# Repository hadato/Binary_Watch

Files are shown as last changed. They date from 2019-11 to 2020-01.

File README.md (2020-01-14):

# Binary Watch

This is a project of binary watch which is able to show time, date and its battery level. Three side LEDs show what is currently on display. The watch is based on an ATMega328p and a PCF8563 real-time clock. All control is done using one press bottom. Light-sensing is implemented for brightness adjustments. 

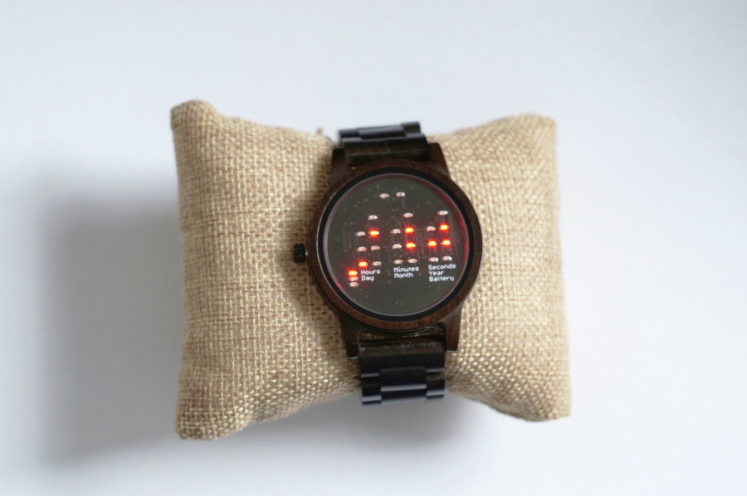
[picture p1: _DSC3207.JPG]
Final prototype


## Description

### Repository and Project Status

The repository contains a first prototype of the watch to be implemented in a wooden hand watch. Both source code, board design files are included. The first prototype has been implemented on a breadboard and is fully functional. The second prototype was build in a wooden wrist watch and is fully functional.

### Main Watch Components
- 25 LEDs
- ATMega328p microcontroller
- PCF8563 real-time clock
- Small tactile switch
- MCP73831T Li-Ion battery charger
- Rechargeable 2032 Li-Ion battery
- Phototransistor for LED intensity adjustment
- USB connector for charging

### Working Principle

The main part of the project is based on an 8-bit microcontroller (uC) ATMega328p connected to the PCF8563 real-time clock (RTC) using I2C. The RTC keeps the correct time, whereas the uC is responsible for all logical operations, inputs from the button and LED output. When the button is pressed, the uC wakes up and the current time is read from the RTC. The time (hours, minutes, seconds) is displayed in a binary-coded decimal (BCD) format on the LEDs using multiplexing. If the button is pressed shortly once more, date (day, month, year) is displayed. Third short press shows the battery voltage. Another short press puts the uC to the sleep mode again. If the button is not pressed for more than 8 s, the uC goes to the sleep mode and all LED are turned off. If a longer press is performed, the watch goes into the sleep mode from either of the previous states. 

To enter the time-setting mode, the button has to be pressed for more than 1 s in either of the previously mentioned modes. If the time-setting mode is entered, a variable to be set starts to blink (first, variable second starts to blink). A short press increments the corresponding variable, longer press (over 0.25s) moves to the next variable (seconds -> minutes -> hours -> day -> month -> year), extra long press confirms the changes and makes the watch to return to the time-display mode.

To save the energy during the run-time and minimize the parts-count, the uC runs on an internal 1 MHz oscillator.

### Code

Note: As included, the code is working though it is still under development and far from being optimal.

The watch is programmed in C++ and is split into three different parts. For the communication with the RTC, twi.h and twi.cpp files were created. For the basic watch operation (button press, LED multiplexing, time reading/setting) a watch.h and watch.cpp files were created. The main.cpp then binds everything together. 

### Board Design

The board is designe using EAGLE and its lates version (9.5.1). The file Top_final shows a look of the watch, the files Top_copper and Bot_copper show the board design. Files BinaryWatch_v0_4_OptR_fix are the EAGLE files.

## Future Goals

- Improve the coding and commenting
- Making a more versatile design which can be used in different watches ranging from tiny hand watches to table/wall watches.
- Implement USB communication with PC to be able to conveniently set up time on the watch (different uC needed).

## Other Pictures
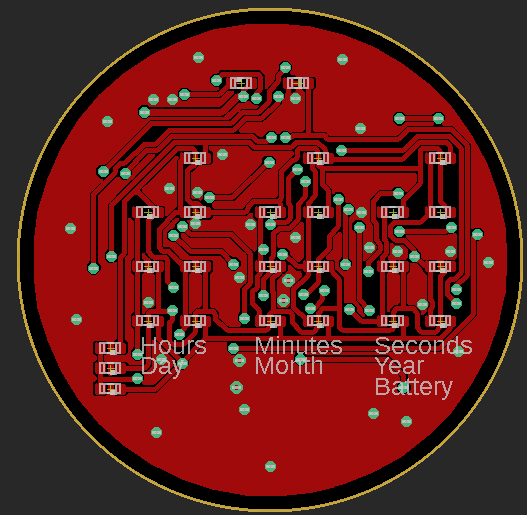
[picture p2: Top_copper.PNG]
TopCopper

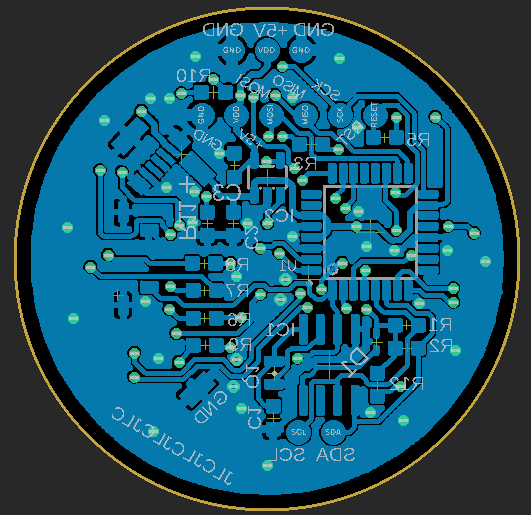
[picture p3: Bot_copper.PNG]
BotCopper

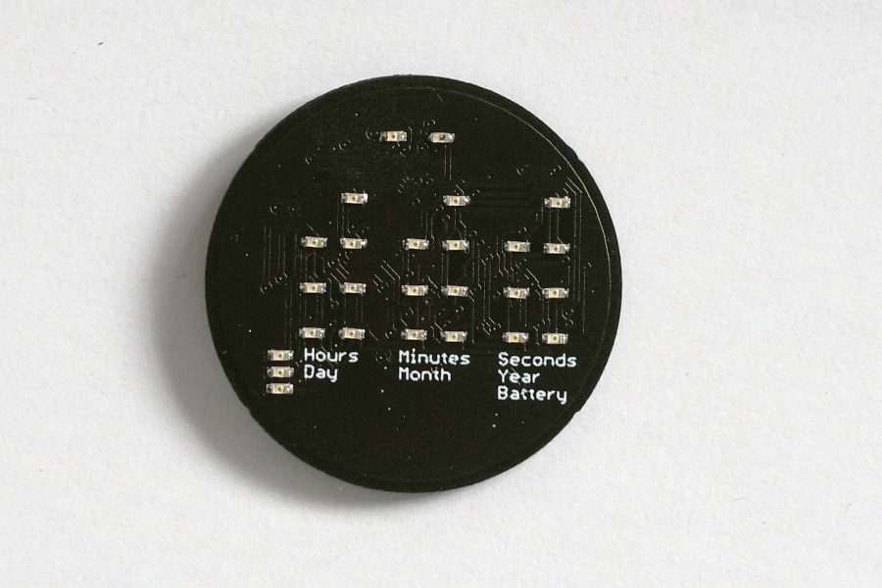
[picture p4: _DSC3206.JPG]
Top

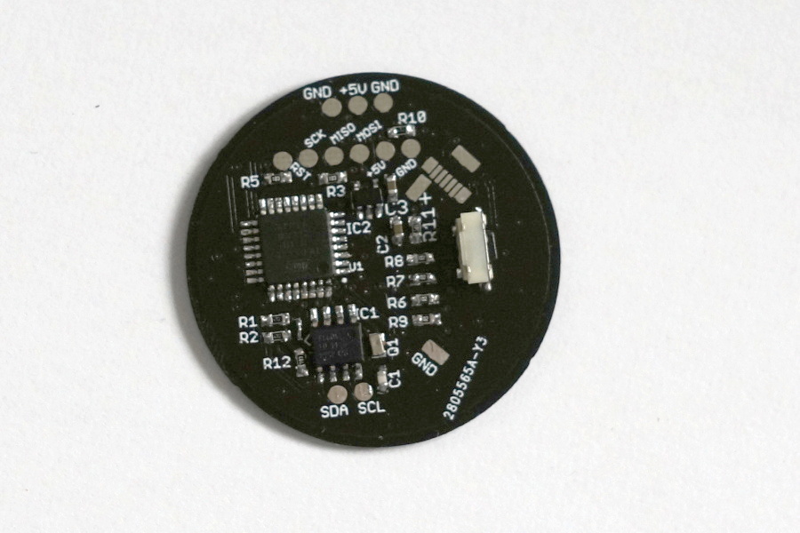
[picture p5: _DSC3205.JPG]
Bot


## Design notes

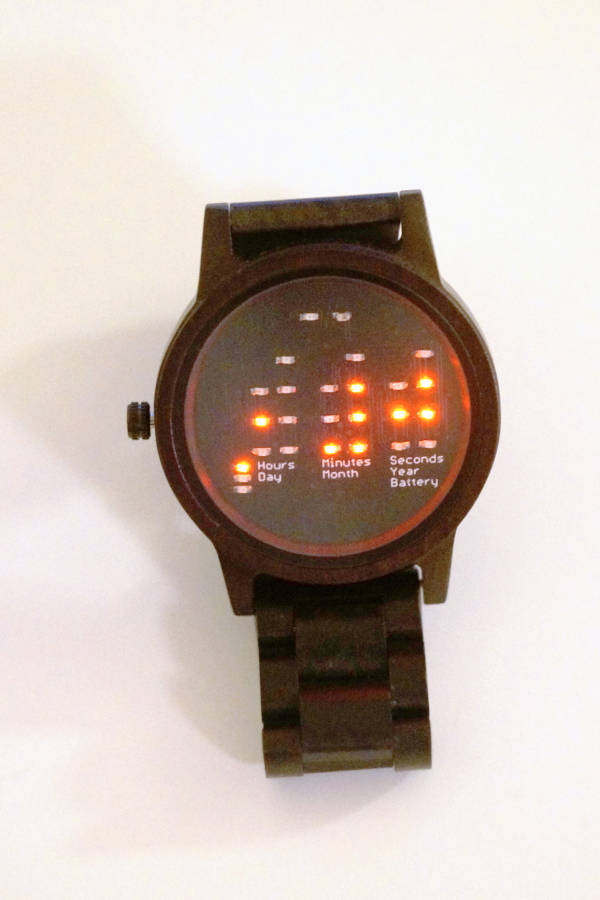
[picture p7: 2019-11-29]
FinalPototype.jpg

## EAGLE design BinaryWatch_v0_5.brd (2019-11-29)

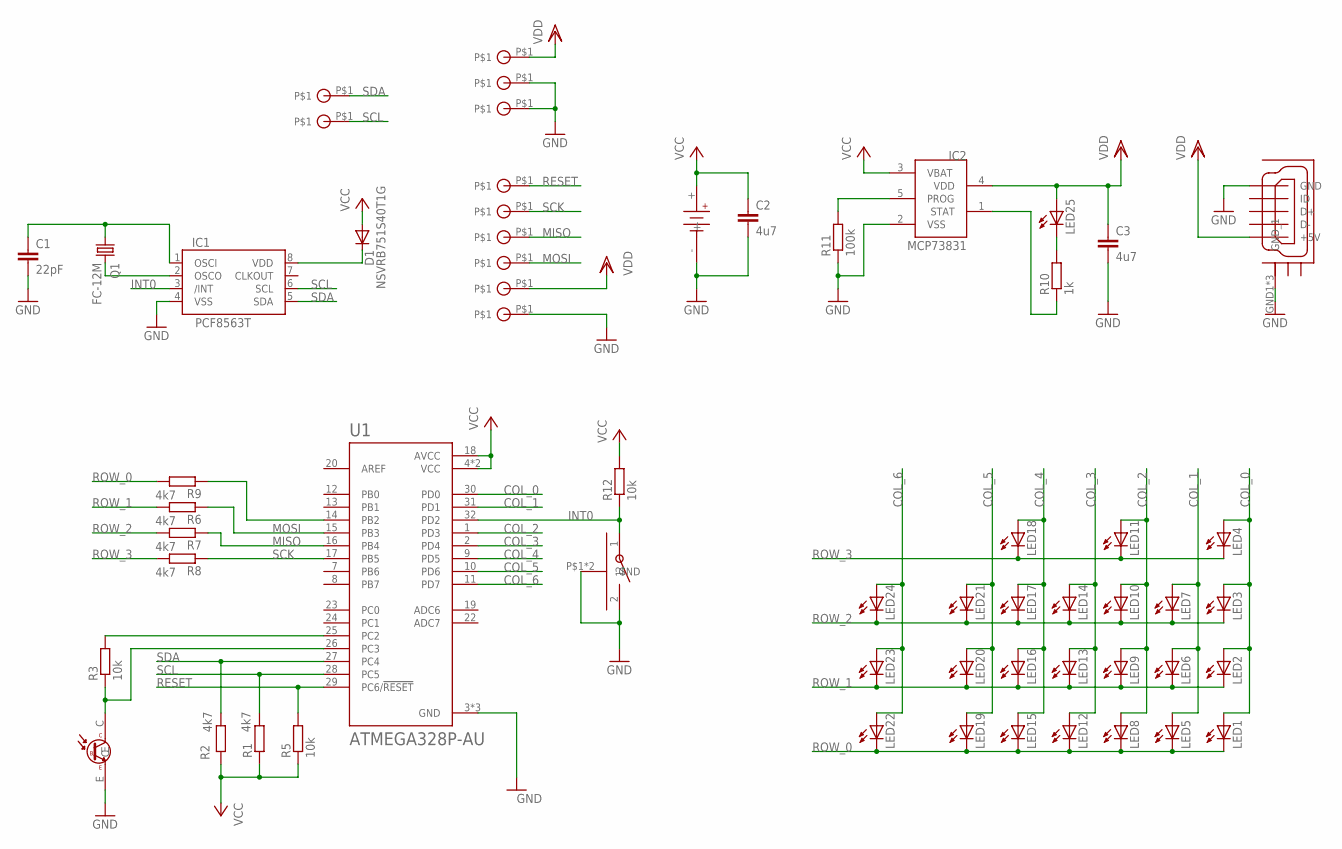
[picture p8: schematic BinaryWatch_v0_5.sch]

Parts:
C1: 22pF; C0603
C2, C3: 4u7; C0603
D1: NSVRB751S40T1G; SOD523
IC1: PCF8563T; SO8
IC2: MCP73831; SOT23-5L
LED1, LED2, LED3, LED4, LED5, LED6, LED7, LED8, LED9, LED10, LED11, LED12, LED13, LED14, LED15, LED16, LED17, LED18, LED19, LED20, LED21, LED22, LED23, LED24, LED25: LEDSML0603; SML0603
Q1: FC-12M
R1, R2, R6, R7, R8, R9: 4k7; R0603
R3, R5, R12: 10k; R0603
R10: 1k; R0603
R11: 100k; R0603
U1: ATMEGA328P-AU; QFP80P900X900X120-32N
U$1: 2032; 2032_45DEG
U$2, U$3, U$4, U$5, U$6, U$7, U$9, U$11, U$12, U$13, U$14: CONTACT_1_8MM
U$8: TACK_SWITCH; TL3330
U$10: MICRO_USB_VERTICAL
U$15: PHOTOTRANSISTOR_0603; PHOTO_TRANS_0603

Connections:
COL_0: LED1.A, LED2.A, LED3.A, LED4.A, U1.30 (PD0)
COL_1: LED5.A, LED6.A, LED7.A, U1.31 (PD1)
COL_2: LED8.A, LED9.A, LED10.A, LED11.A, U1.1 (PD3)
COL_3: LED12.A, LED13.A, LED14.A, U1.2 (PD4)
COL_4: LED15.A, LED16.A, LED17.A, LED18.A, U1.9 (PD5)
COL_5: LED19.A, LED20.A, LED21.A, U1.10 (PD6)
COL_6: LED22.A, LED23.A, LED24.A, U1.11 (PD7)
GND: C1.2, C2.2, C3.2, IC1.4 (VSS), IC2.2 (VSS), R11.1, U1.3 (GND), U1.5 (GND), U1.21 (GND), U$1.-, U$2.P$1, U$8.2, U$8.P$1 (GND), U$8.P$2 (GND), U$9.P$1, U$10.5 (GND), U$10.GND1 (GND_1), U$10.GND2 (GND_1), U$10.GND3 (GND_1), U$12.P$1, U$15.E
INT0: IC1.3 (/INT), R12.1, U1.32 (PD2), U$8.1
MISO: R7.1, U1.16 (PB4), U$5.P$1
MOSI: R6.1, U1.15 (PB3), U$4.P$1
unnamed: IC1.2 (OSCO), Q1.2
unnamed: C1.1, IC1.1 (OSCI), Q1.1
unnamed: R3.1, U1.26 (PC3), U$15.C
unnamed: R3.2, U1.25 (PC2)
unnamed: R9.1, U1.14 (PB2)
unnamed: D1.C, IC1.8 (VDD)
unnamed: IC2.1 (STAT), R10.1
unnamed: LED25.C, R10.2
unnamed: IC2.5 (PROG), R11.2
RESET: R5.2, U1.29 (PC6/!RESET), U$7.P$1
ROW_0: LED1.C, LED5.C, LED8.C, LED12.C, LED15.C, LED19.C, LED22.C, R9.2
ROW_1: LED2.C, LED6.C, LED9.C, LED13.C, LED16.C, LED20.C, LED23.C, R6.2
ROW_2: LED3.C, LED7.C, LED10.C, LED14.C, LED17.C, LED21.C, LED24.C, R7.2
ROW_3: LED4.C, LED11.C, LED18.C, R8.2
SCK: R8.1, U1.17 (PB5), U$6.P$1
SCL: IC1.6 (SCL), R1.2, U1.28 (PC5), U$14.P$1
SDA: IC1.5 (SDA), R2.2, U1.27 (PC4), U$13.P$1
VCC: C2.1, D1.A, IC2.3 (VBAT), R1.1, R2.1, R5.1, R12.2, U1.4 (VCC), U1.6 (VCC), U1.18 (AVCC), U$1.+
VDD: C3.1, IC2.4 (VDD), LED25.A, U$3.P$1, U$10.1 (+5V), U$11.P$1

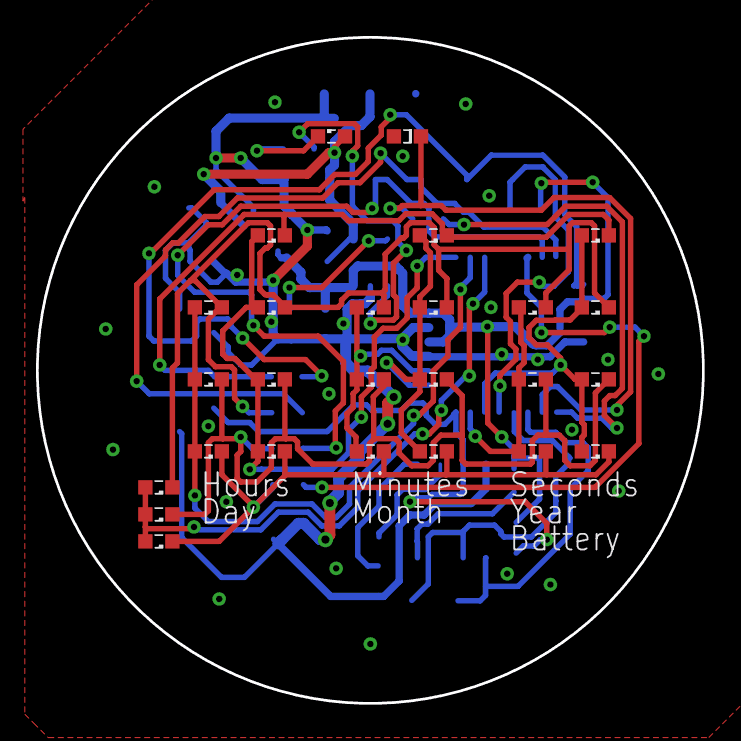
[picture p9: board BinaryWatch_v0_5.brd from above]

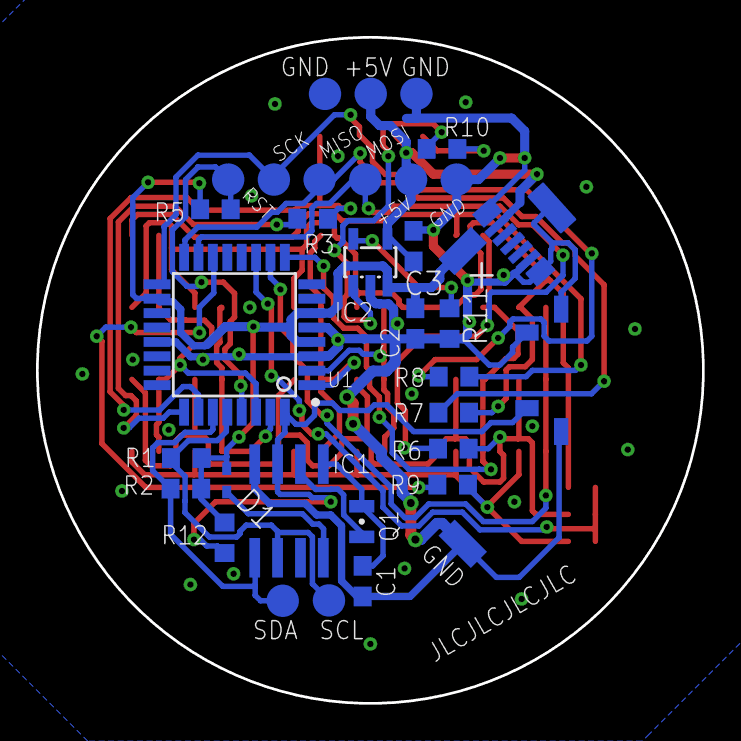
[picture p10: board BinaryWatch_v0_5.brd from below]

Board: 2 copper layers, 37.0 x 37.0 mm, 59 parts (33 on the bottom side), 30 nets.

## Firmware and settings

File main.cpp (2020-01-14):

/*
 * BinaryWatch_v0.1.cpp
 * Blink Test
 * Created: 7.10.2019 10:56:57
 * Author : Hadato
 */ 

#define F_CPU 1000000UL

#include <avr/io.h>
#include <util/delay.h>
#include <stdlib.h>
#include <avr/interrupt.h>
#include <avr/sleep.h>

#include "twi.h"
#include "watch.h"

int main(void){		
	//Wait for the power to get settled
	cli();
	_delay_ms(500);
	
	
	//Initialize the watch including all its functions	
	watch::init();		
		
	//Turn on all the LEDs for 1s to show that the chip has started working		
	WRITE_PORT(PORTB,0b00000000,0b00111100);
	WRITE_PORT(PORTD,0b11111111,0b11111011);
	
	_delay_ms(2000);
	sei();	
    
    while (1){
		
		
		_delay_ms(10);		
			
		//Update the time from the RT clock and save it to corresponding internal watch variables
		watch::update_TimeDate();
		
		//Measure the voltage and light intensity and set the LED brightness accordingly
 		watch::set_LED_intensity(watch::light);	//Set the intensity of LEDs accordingly
		watch::ADC_get_supply_light();			//Measure the supply voltage and the light intensity
		
		//Send the info to Arduino
		// watch::sentToArduino(watch::light);
		
		//Has to be called in the loop in order to get the state machine to work
		if(watch::pressed){			
			//Change the internal system state			
			watch::state = watch::state_machine(watch::state,watch::pressed);
			watch::pressed = NOT;			
		}
		
		//If the state is set to GO_SLEEP, turn-off all the LEDs and sleep the uC. Wake up and update after the sleep
		if (watch::state == GO_SLEEP){
			_delay_ms(20);
			//Disable all not needed modules and set all LED outputs low
			watch::set_all_pins_low_LED();				// Set all LED outputs low to save energy
			watch::ADC_disable();						// Disable ADC			
			//watch::PRR_disable_all();					// DIsable all modules in the sleep mode
			twi::disable_pull_ups();					// Disable pull-ups on TWI
			
			
			//Prepare for sleep and sleep
			sleep_enable();						//Enable sleep mode
			EIMSK  |= (1 << INT0);				//Turns on INT0 to enable wake up of the uC
			sleep_cpu();						//Go to sleep		
			
			//After sleep
			sleep_disable();
			watch::PRR_enable_ADC_Timer0();		//Turn on just the ADC and Timer0
				
			uint8_t voltage_low = 1;		
			while (voltage_low){
				watch::PRR_enable_ADC_Timer0();	//Turn on just the ADC and Timer0
				watch::ADC_get_supply_light();
				_delay_ms(15);					//Wait for the voltage measurement to complete
				if (watch::u_supply < 2.9){
					//watch::PRR_disable_all();		//Turn off all peripherals
					watch::set_all_pins_low_LED();	// Set all LED outputs low to save energy
					watch::ADC_disable();			// Disable ADC
					sleep_enable();
					sleep_cpu();
					sleep_disable();
				}else{
					voltage_low = 0;
				}
			}
			
			
			cli();						//Disable interrupts to safely change states and PRR register
			watch::PRR_enable_ADC_Timers_TWI();			//Turn on all peripherals except SPI and USART0
			
			
			// After sleep update of states and time from the watch. Disable the sleep, enable the 
			// pull-ups on Twi		
			twi::enable_pull_ups();		//Enable pull-ups on TWI
			
			//Reset internal states after sleep
			watch::pressed = NOT;
			watch::state   = AFTER_SLEEP;
				
			sei();						//Enable interrupts			
			
			//Update time and date and save it to the variables
			watch::set_LED_intensity(200);
			watch::update_TimeDate();					
		}			
    }
}

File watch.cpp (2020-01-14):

/*A source file for multiplexing
*	Timer0 is used for multiplexing
*	Timer1 is used for the button press and general timing needs
*
*
*/

#include "watch.h"
#include <avr/io.h>
#include <stdlib.h>
#include "twi.h"
#include <avr/interrupt.h>
#include <avr/sleep.h>

namespace watch{
	//Variables to store the current time from the RT clock
	Time time_DEC;			//Current time in DEC format
	Time time_BCD;			//Current time in BCD format
	Time time_DEC_new;		//New time to be set on the watch in DEC format
	Time time_BCD_new;		//New time to be set on the watch in BCD format
	uint8_t col;			//A variable to store current column to be displayed - used for multiplexing
	uint16_t press_how_long = 0;	//An internal variable to determine the length of the press
	uint8_t pressed = NOT;			//A variable for the length of the last press. Set to not-pressed
	float battery_level = 0;		//A variable to store the battery level (initialized to 0)
	State state = GO_SLEEP;			//A variable to indicate the current state of the watch. Set to enter the sleep mode
	float u_supply = 0;				//A variable to store the current voltage of the battery
	uint16_t u_supply_sum= 0;		//Raw sum of the battery voltage readouts
	float u_supply_show = 0;		//A variable to store the voltage of the battery to be displayed on the LEDs
	uint16_t blink_counter = 0;		//A counter for blinking function
	bool blink = true;				//Should the LEDs blink?
	uint8_t error = 0;				//An internal error variable
	uint8_t light = 255;			//A variable to store how much light it is outside (values from 0 (high light) - 255 (low light))
	uint8_t light_vect[] = {255,255,255,255};
	uint16_t light_sum = 0;
	adc_stat ADC_stat = MEASURE_LIGHT;		//A variable to store the ADC internal state
	uint8_t adc_counter = 0;				//Counter for the light average
	
	//Instance of the Twi class - communication with the RT clock
	twi Twi;	
}



ISR(BADISR_vect)
{
	// skip a random interrupt
}

////////////////////LED multiplexing and visualization //////////////////////////////// 
ISR(TIMER2_COMPA_vect){
	//dim the LEDs according to the light
	watch::clear_LED();
}

ISR(TIMER2_COMPB_vect){
	//set the LEDs according to what should be shown
	watch::ISR_handler();		//Turn on the correct LEDs	
}

//////////////////Functions to handle bottom interrupts/////////////////////////////
ISR (INT0_vect)
{
	EIMSK &= ~(1 << INT0);		//Turns off INT0
	TIMSK1 |= (1 << OCIE1A)|(1 << OCIE1B);	//Enable Timer1 on compare match A and B
	TCNT1  = 0;					//Reset timer1 counter	
}

ISR (TIMER1_COMPA_vect){
	EIMSK  |= (1 << INT0);		//Turns on INT0
	TIMSK1 &= ~((1 << OCIE1B)|(1 << OCIE1A));	//Disables Timer1 on compare match A and B
	watch::state = GO_SLEEP;
}

ISR (TIMER1_COMPB_vect){
	TCNT1  = 0;				//set the counter to 0	
	
	//Check for the bounce and how long the press holds
	
	//If pressed, increment the counter
	if ((PIND & (1<<PIND2)) == 0){
		watch::press_how_long++;
	}
	//If not pressed, determine how long the press was
	else{if (watch::press_how_long >= EX_LONG_PRESS){
			//PORTB |= LED_ON;
			watch::pressed = EX_LONG;
		}else if (watch::press_how_long >= LONG_PRESS){
			//PORTB |= LED_ON;
			watch::pressed = LONG;
		}else if (watch::press_how_long >= SHORT_PRESS){
			//PORTB |= LED_ON;
			watch::pressed = SHORT;
		}else if (watch::press_how_long < SHORT_PRESS){
			//PORTB &= LED_OFF;
			watch::pressed = NOT;
		}
		watch::press_how_long = 0;
		EIMSK  |= (1 << INT0);		//Turns on INT0	
		TIMSK1 &= ~(1 << OCIE1B);	//Disables Timer1 on compare match B
	}
}


///////////////////////////////////////////////////////////////////////////////////////////////
// ADC, voltage and light measurements
// To measure the light, supply voltage is measured first, then, the light intensity is
// scaled accordingly
// First,
//
// After calling watch::ADC_get_supply_light(), timer0 is started to enable the voltage
// on the internal reference to settle. After ca. 10 ms, the measurement of the battery
// voltage is started. After done, an ADC interrupt is triggered. In order to get more
// precise measurement, the voltage is measured 16 times and averaged before the actual
// light measurement is performed. The battery voltage is stored in a variable 
// watch::u_supply. The light intensity is measured 8 times and the average is returned 
// and saved in watch:.light .

ISR(ADC_vect){
	// Interrupt handler for the ADC
	// If measuring battery, save to the watch::u_supply and then measures the light intensity and 
	// saves to watch::light. If done, disable the ADC
	
	sei();		//Enable the ISR to be interrupted by other interrupts
	
	//If measuring the battery
	if (watch::ADC_stat == MEASURE_SUPPLY)	{
		// Average 8 measurements together to eliminate the ripple
		if (watch::adc_counter < 16){
			watch::adc_counter++;
			watch::u_supply_sum += ADC;		// add the ADC readout to the voltage sum
			watch::ADC_start();
		}else{		
			watch::adc_counter = 0;					// zero the adc_coutner
			
			// AVcc = Vbg/ADC*1023 = 1.1V*1023/ADC - Use the average u_supply_sum instead fo the ADC
			watch::u_supply = (1.1*1023/(watch::u_supply_sum >> 4));
					
			watch::u_supply_sum = 0;				// zero the average supply voltage sum
			watch::ADC_get_light();					// start the light measurement
		}
		
	//If measuring the light
	}else if(watch::adc_counter < 8){
		// Average 8 measurements to eliminate the ripple 
		watch::adc_counter++;
		watch::light_sum += ADC;
		watch::ADC_start();	
		
	//If done, disable the ADC and clear the variables
	}else{
		watch::adc_counter = 0;
		watch::ADC_disable();
		watch::light = watch::light_sum >> 5;
		watch::light_sum = 0;
	}
}

ISR (TIMER0_COMPA_vect){
	// Timer0 interrupt used to wait before the battery voltage is measured
	watch::ADC_timer0_stop();
	sei();		//Enable the interrupt being interrupted by other interrupts
	watch::ADC_start();
}


void watch::ADC_timer0_init(){
	// set up timer with CTC mode and prescaler = 256
	TCCR0A |= (1 << WGM01);		//Set CTC mode
	TCCR0B |= (1 << CS02);		//Set prescaler to 256
	
	// initialize counter
	TCNT0 = 0;
	
	// set the frequency to ca 200 Hz
	OCR0A = 39; //set to 200 Hz (78 for 50 Hz)
}

void watch::ADC_timer0_start(){
	//Start the timer0 with correct mode
	TCNT0	= 0;				//Zero the timer counter
	TIMSK0 |= (1 << OCIE0A);	//Set interrupt on compare A match
}

void watch::ADC_timer0_stop(){
	// Stop the timer0
	TIMSK0 &= ~(1 << OCIE0A);	//Disable interrupt on compare A match
}

void watch::ADC_init(){
	// Initializes ADC with correct frequency
	ADCSRA  = (1 << ADPS2) | (1 << ADIE);   //Set prescaler to 16 - 62500 Hz and enable interrupts from ADC
	ADMUX  |= (1 <<REFS0);					//Set reference to AVCC
	ADC_timer0_init();						//Initialize timer0 for the delayed measurements of power supply voltage
	
	//ADC
	DDRC  |= (1 << PC2);	// set PC2 as output
	PORTC |= (1 << PC2);	// set PC2 high - turn the power up for the photo-resistor
}

void watch::ADC_enable(){
	ADCSRA |= (1 << ADEN);	//Enable ADC
}
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

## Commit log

2019-11-11 Repo created on GitHub
    Final prototype version of the watch
    [BinaryWatch_v0_4_OptR_fix.brd, BinaryWatch_v0_4_OptR_fix.sch]
2019-11-11 Updated README.md with Board Design
2019-11-29 Added final version of the prototype
2019-11-29 Updated README with prototype picture
    A wooden hand watch prototype has been added
2019-11-29 Added new board files
    [BinaryWatch_v0_5.brd, BinaryWatch_v0_5.sch]
2019-11-29 Deleting old bord files
    [BinaryWatch_v0_4_OptR_fix.brd]
2019-11-29 Deleting old schematic
    [BinaryWatch_v0_4_OptR_fix.sch]
